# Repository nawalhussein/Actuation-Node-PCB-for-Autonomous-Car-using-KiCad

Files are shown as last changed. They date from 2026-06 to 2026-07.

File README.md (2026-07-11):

# STM32 Actuator Control Board PCB

This project contains the complete hardware design (schematics and PCB layout) and associated software for a custom-built STM32-based actuator control system to be put in the autonomous car.

### Brief Project Description

This PCB is designed as a centralized control hub for multiple DC motor actuators in an autonomous or complex electro-mechanical system (e.g., an agribot, mobile robot, or robotic manipulator).

At its core is an STM32 "BluePill" microcontroller. The board interfaces with various components to manage complex movement:

* **Microcontroller:** An STM32F103 (BluePill) provides the processing logic.
* **Actuator Drivers:** Integrated circuits (represented by connectors in the current schematic iteration) control multiple DC motors with direction (`DIR`) and pulse-width modulation (`PWM`) speed signals.
* **Control Input:** It receives motion and velocity commands via a high-level **CAN bus** or standard **UART** serial communication.
* **Feedback (ADC):** Analog inputs monitor potentiometer-based sensors (e.g., steering and brake feedback) for precise position sensing.
* **Interface (DAC):** A Digital-to-Analog converter provides fine-tuned analog voltage output.
* **Level Shifting:** Bidirectional level shifters ensure logic compatibility between 3.3V signals (like `STEP_EN`, `DIR_REAR_BRAKE`) and other standard 5V peripherals.
* **Safety:** A robust protection circuit with a reverse-voltage blocking diode and a fast-acting fuse ensures system reliability.
* **Expandability:** Multiple power sources and extra GPIO headers are included for external sensor integration and future features.

---

### Project Repository Contents

* `/hardware/`: Kicad design files (schematic and PCB)
* `/docs/`: PDF for the PCB and schematic

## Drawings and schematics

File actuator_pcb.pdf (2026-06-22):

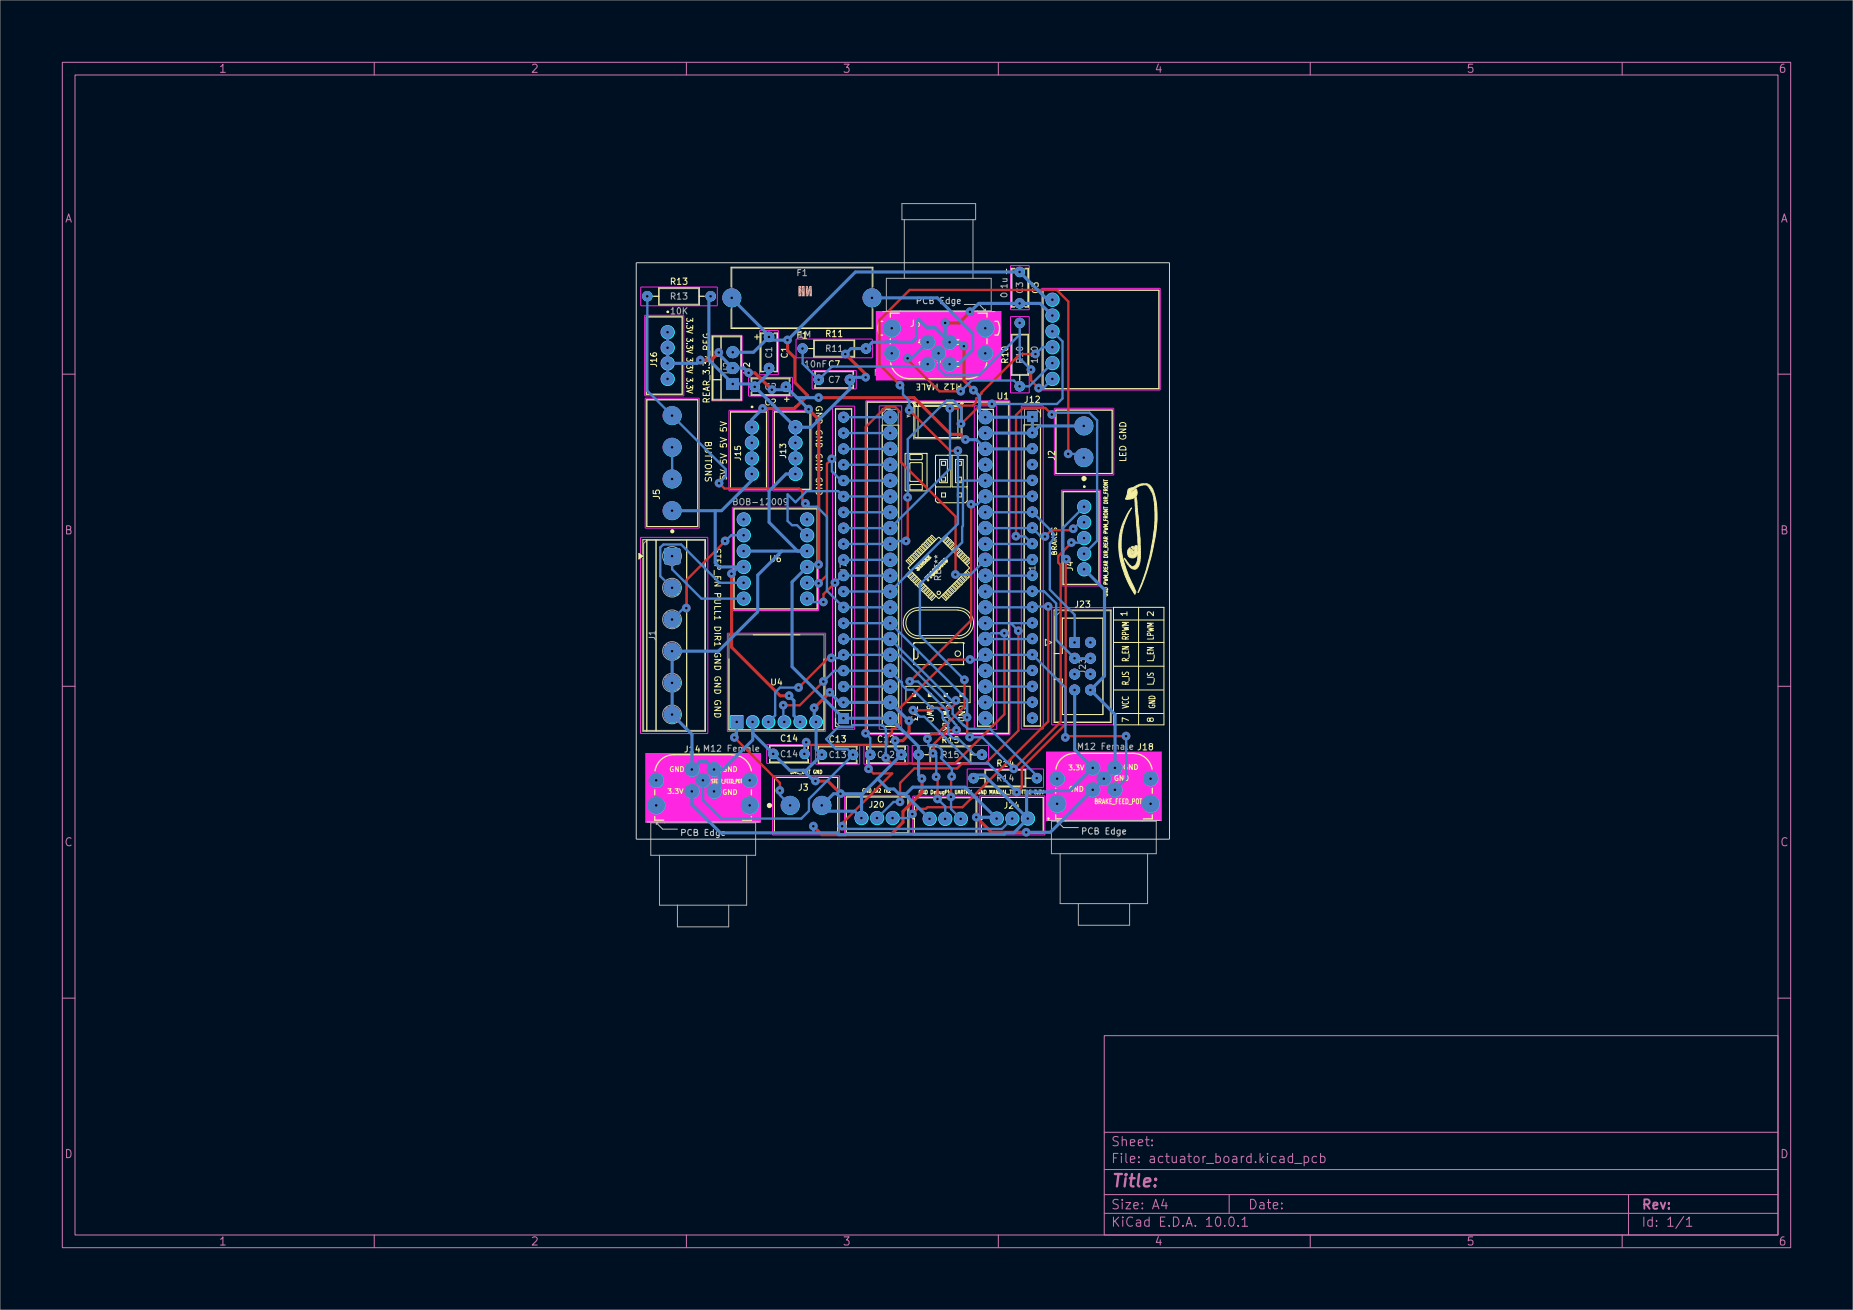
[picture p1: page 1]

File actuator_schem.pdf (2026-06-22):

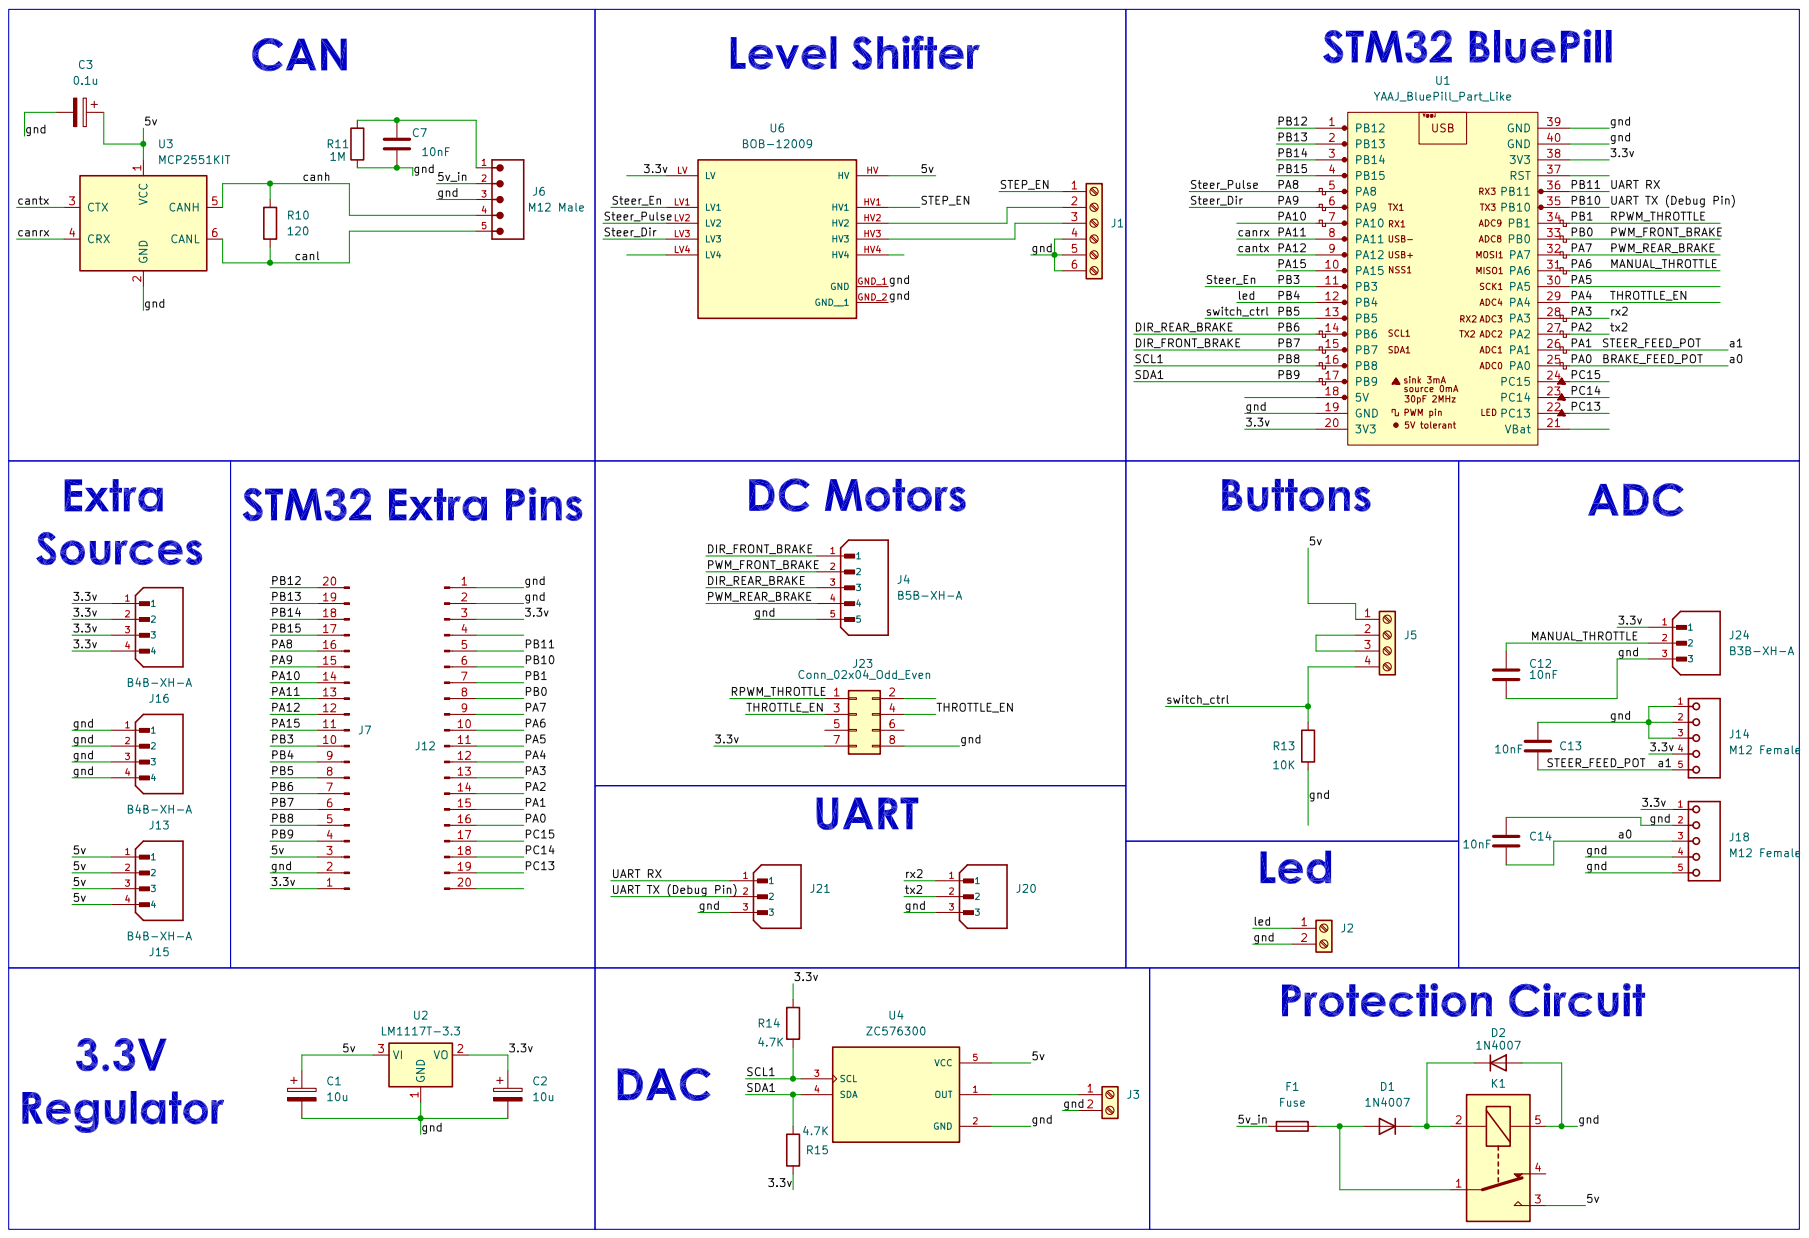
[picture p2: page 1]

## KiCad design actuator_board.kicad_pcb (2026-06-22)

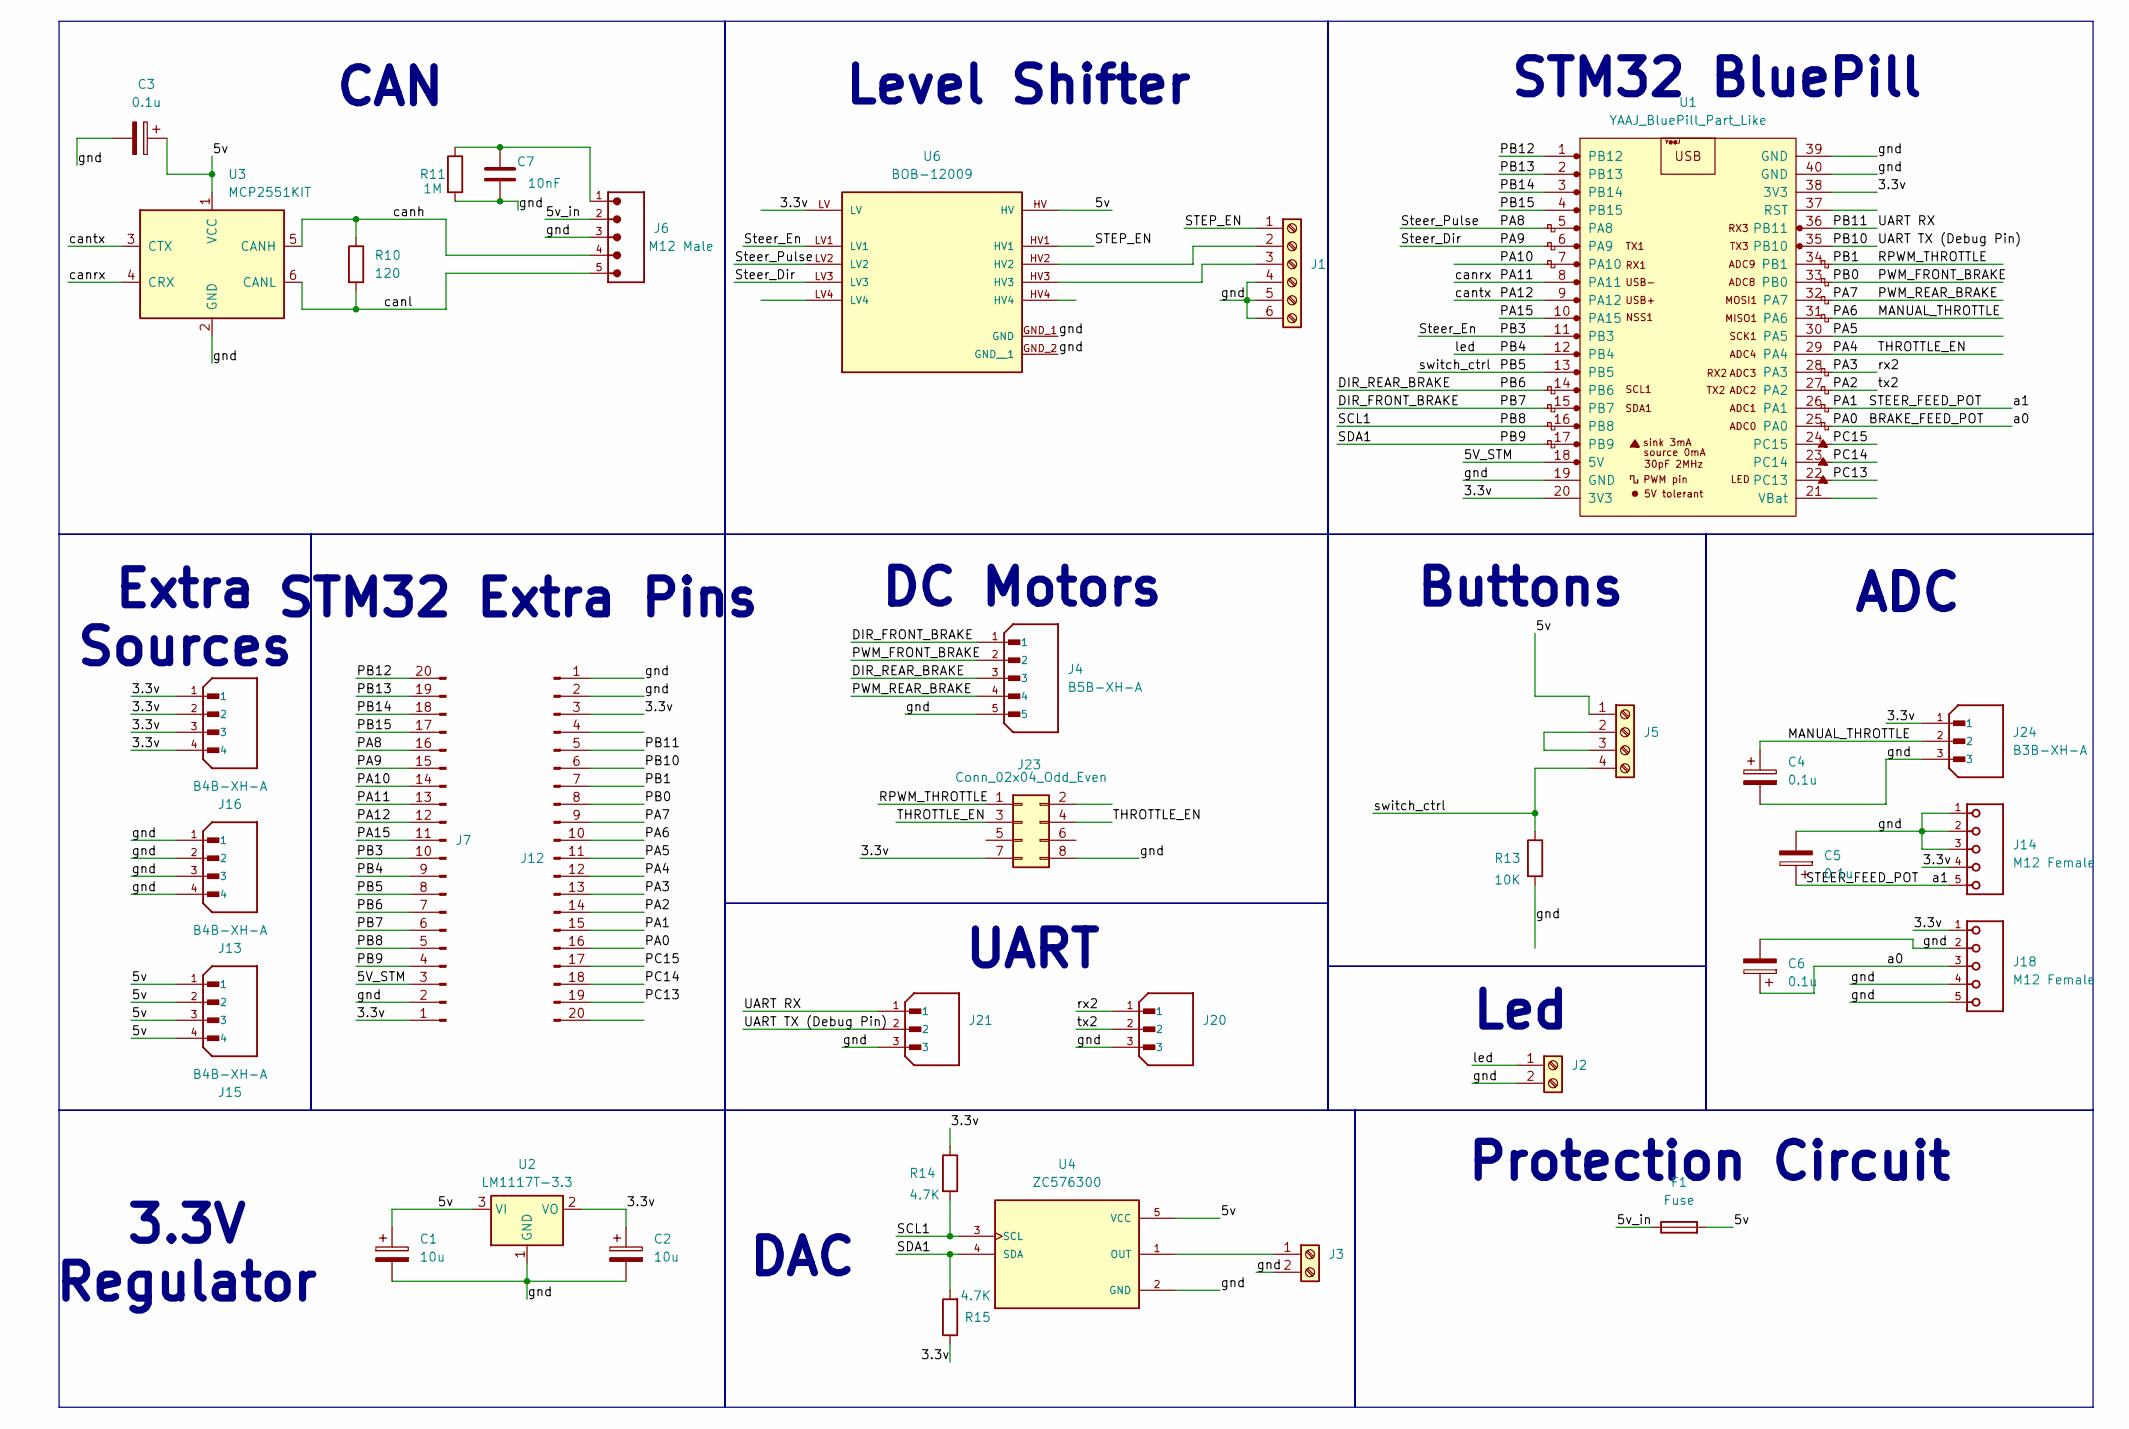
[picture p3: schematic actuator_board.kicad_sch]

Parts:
C1, C2: 10u; C_Disc_D6.0mm_W2.5mm_P5.00mm
C3, C4, C5, C6: 0.1u; C_Disc_D6.0mm_W2.5mm_P5.00mm
C7: 10nF; C_Disc_D6.0mm_W2.5mm_P5.00mm
F1: Fuse; Fuseholder_Cylinder-5x20mm_Schurter_0031_8201_Horizontal_Op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
J1: Screw_Terminal_01x06; TerminalBlock_Phoenix_MKDS-1,5-6-5.08_1x06_P5.08mm_Horizont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
J2, J3: Screw_Terminal_01x02; TE_282841-2
J4: B5B-XH-A; JST_B5B-XH-A; PARTREV 7/4/21
J5: Screw_Terminal_01x04; TE_282837-4
J6: M12 Male; 643270100305
J7, J12: Conn_01x20_Pin; PinSocket_1x20_P2.54mm_Vertical
J13, J15, J16: B4B-XH-A; JST_B4B-XH-A; PARTREV .
J14, J18: M12 Female; 643280100305
J20, J21, J24: B3B-XH-A; JST_B3B-XH-A; PARTREV .
J23: Conn_02x04_Odd_Even; IDC-Header_2x04_P2.54mm_Vertical
R10: 120; R_Axial_DIN0207_L6.3mm_D2.5mm_P10.16mm_Horizontal
R11: 1M; R_Axial_DIN0207_L6.3mm_D2.5mm_P10.16mm_Horizontal
R13: 10K; R_Axial_DIN0207_L6.3mm_D2.5mm_P10.16mm_Horizontal
R14, R15: 4.7K; R_Axial_DIN0207_L6.3mm_D2.5mm_P10.16mm_Horizontal
U1: YAAJ_BluePill_Part_Like; YAAJ_BluePill_1
U2: LM1117T-3.3; TO-220-3_Vertical
U3: MCP2551KIT; mcp2551kit
U4: ZC576300; MODULE_ZC576300; PARTREV v14
U6: BOB-12009; CONV_BOB-12009; PARTREV 01

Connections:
/3.3v: C2.1, J7.1, J12.3, J14.4, J16.1, J16.2, J16.3, J16.4, J18.1, J23.7, J24.1, R14.1, R15.1, U1.20 (3V3), U1.38 (3V3), U2.2 (VO), U6.LV
/5V_STM: J7.3, U1.18 (5V)
/5v: C1.1, C3.1, F1.2, J5.1, J15.1, J15.2, J15.3, J15.4, U2.3 (VI), U3.1 (VCC), U4.5 (VCC), U6.HV
/5v_in: F1.1, J6.2
/BRAKE_FEED_POT: C6.1, J12.16, J18.3, U1.25 (PA0)
/DIR_FRONT_BRAKE: J4.1, J7.6, U1.15 (PB7)
/DIR_REAR_BRAKE: J4.3, J7.7, U1.14 (PB6)
/MANUAL_THROTTLE: C4.1, J12.10, J24.2, U1.31 (PA6)
/PA1: C5.1, J12.15, J14.5, U1.26 (PA1)
/PA2: J12.14, J20.2, U1.27 (PA2)
/PA3: J12.13, J20.1, U1.28 (PA3)
/PA4: J12.12, J23.3, J23.4, U1.29 (PA4)
/PA5: J12.11, U1.30 (PA5)
/PA7: J4.4, J12.9, U1.32 (PA7)
/PA8: J7.16, U1.5 (PA8), U6.LV2
/PA9: J7.15, U1.6 (PA9), U6.LV3
/PA10: J7.14, U1.7 (PA10)
/PA11: J7.13, U1.8 (PA11), U3.4 (CRX)
/PA12: J7.12, U1.9 (PA12), U3.3 (CTX)
/PA15: J7.11, U1.10 (PA15)
/PB0: J4.2, J12.8, U1.33 (PB0)
/PB1: J12.7, J23.1, U1.34 (PB1)
/PB3: J7.10, U1.11 (PB3), U6.LV1
/PB4: J2.1, J7.9, U1.12 (PB4)
/PB5: J5.4, J7.8, R13.1, U1.13 (PB5)
/PB8: J7.5, R14.2, U1.16 (PB8), U4.3 (SCL)
/PB9: J7.4, R15.2, U1.17 (PB9), U4.4 (SDA)
/PB10: J12.6, J21.2, U1.35 (PB10)
/PB11: J12.5, J21.1, U1.36 (PB11)
/PB12: J7.20, U1.1 (PB12)
/PB13: J7.19, U1.2 (PB13)
/PB14: J7.18, U1.3 (PB14)
/PB15: J7.17, U1.4 (PB15)
/PC13: J12.19, U1.22 (PC13)
/PC14: J12.18, U1.23 (PC14)
/PC15: J12.17, U1.24 (PC15)
/STEP_EN: J1.1, U6.HV1
/canh: J6.4, R10.1, U3.5 (CANH)
/canl: J6.5, R10.2, U3.6 (CANL)
GND: C1.2, C2.2, C3.2, C4.2, C5.2, C6.2, C7.2, J1.4, J1.5, J1.6, J2.2, J3.2, J4.5, J6.3, J7.2, J12.1, J12.2, J13.1, J13.2, J13.3, J13.4, J14.1, J14.2, J14.3, J18.2, J18.4, J18.5, J20.3, J21.3, J23.8, J24.3, R11.2, R13.2, U1.19 (GND), U1.39 (GND), U1.40 (GND), U2.1 (GND), U3.2 (GND), U4.2 (GND), U4.6 (GND), U6.GND_1 (GND), U6.GND_2 (GND__1)
unnamed: C7.1, J6.1, R11.1
unnamed: J1.2, U6.HV2
unnamed: J1.3, U6.HV3
unnamed: J3.1, U4.1 (OUT)
unnamed: J5.2, J5.3

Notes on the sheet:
DC Motors
CAN
UART
STM32 Extra Pins
STM32 BluePill
ADC
Led
Level Shifter
Protection Circuit
DAC
Extra Sources
3.3V Regulator
Buttons

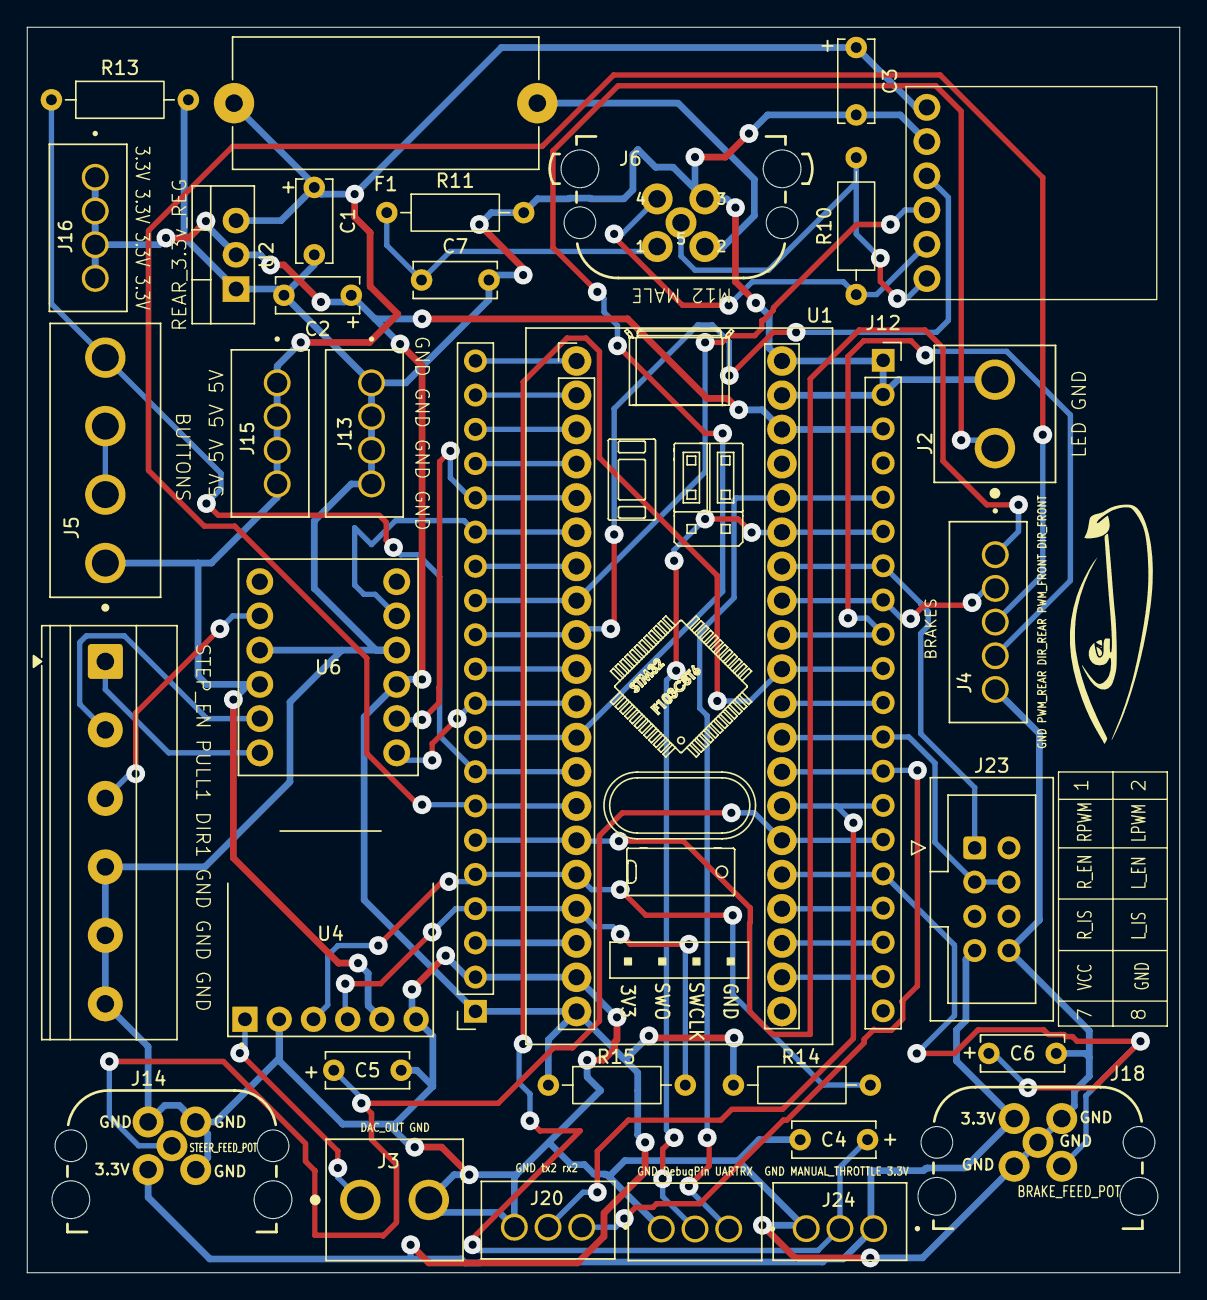
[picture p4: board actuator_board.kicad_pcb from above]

Board: 2 copper layers, 85.5 x 92.4 mm, 35 parts (0 on the bottom side), 45 nets.
